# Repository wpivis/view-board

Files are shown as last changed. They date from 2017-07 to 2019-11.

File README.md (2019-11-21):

# view-board

For our very own [AnyPixel.js](http://googlecreativelab.github.io/anypixel/) board
=========

## Architecture

Project uses a Teensy 3.2 board to control the WS2812 LED strip and buttons, using serial data to communicate. 

## Install

To install the library, simply type this into your nearest console: 
```js
npm install nopixel
```

At this point, depending on the distribution, you may note that your computer is slightly unhappy. This is due to the fact that `nopixel` relies on `serialport` to get access to, well, the serial port. `serialport` however, relies on `node-gyp` which is notoriously hard to build. Therefore I recommend you go to https://github.com/nodejs/node-gyp#installation for your troubleshooting needs.

If installation of `nopixel` still fails, please run 
```js
npm install serialport
```

## Usage

- Flash the firmware found in `firmware/arduino_firmware` to the Teensy. For this you will need to install [Teensyduino](https://www.pjrc.com/teensy/teensyduino.html)
- Create a `config.json` following this template
	```json
	[{
		"comPort": "/name/of/comPort",
		"baudRate": "BAUD_RATE"
	}]
	```
- Run `node app.js` for the example app

### Canvas support

This module supports `node-canvas`. Simply create a 7x7 canvas, then export it to the board using 
```js
	var data = ctx.getImageData(0,0,7,7);
	nopixel.fromCanvas(data);
	nopixel.update();
```
For a working example, look into examples/ConnectFour

### API

#### Events

All nopixel events, with the exception of `ready`, sends back an object `eventDetail` with the coordinates of the button press in the form of 

```js
var eventDetail = {
	x: 	X-coordinate of the button press (0-6),
	y: 	Y-coordinate of the button press (0-6),
	index: 	Index of the button press (0-48)
}
```

#### `.on('ready')`

Emits when established a connection with the board. Throws an error otherwise.

#### `.on('clicked')`

Emits when a button is pressed quickly - aka 'onButtonDown'. Pass an `eventDetail` object.

#### `.on('pressed')`

Emits when a button is held down. Pass an `eventDetail` object.

#### `.on('released')`

Emits when a button is released - aka 'onButtonUp'. Pass an `eventDetail` object.

#### `.on('idle')`

Emits the default state, when nothing is happening. Pass an `eventDetail` object.

#### Functions

#### `.setPixel()`

```js
nopixel.setPixel(x, y, colorObj)
```

Where x,y denotes the coordinates on the board (0-6), and colorString is a valid `tinyColor2` object. Examples includes string input (`"black"`, `"f0f0f6"`, `"rgb (255, 0, 0)"`, `"hsla(0, 100%, 50%, .5)"`), or RGB/RGBA/HSL/HSLA/HSV/HSVA objects (`{ h: 0, s: 1, l: .5 }`)

#### `.update()`

```js
nopixel.update()
```

aka `render`. Pushes and set all changes to LEDs at the same time. This prevents multiple refresh calls to the board and saves clock cycles.

#### `.clear()`

```js
nopixel.clear()
```

Sets all pixels to black, essentially turning them off.

#### `.fromCanvas()`

```js
nopixel.fromCanvas(canvasBuffer)
```

`node-canvas` integration. Takes in a Canvas buffer and send it to the LEDs.

#### `.write()`

```js
nopixel.write(string, colorObj, scrollSpeed)
```

One of the two text writing functions. `.write()` is used for anything more than a single letter, and will scroll the text in `string`, in color `colorObj`, looping indefinitely at a speed (delay between updates) `scrollSpeed`. 

Passes back a `setInterval` object. To stop scrolling use the built-in `clearInterval()`.

For more information check out the `TextDisplay` example.

#### `.writeLetter()`

```js
nopixel.writeLetter(letter, colorObj, x, y)
```

The other text writing function. As opposed to `.write()`, `.writeLetter()` as the name suggests, only prints one `letter` at a time, in color `colorObj`, starting at coordinates `x` `y`.

Fonts configuration is stored in `letters.json` as two-dimentional arrays, with 1 as filled, and 2 as unfilled - feel free to change them as you see fit.

### Opcodes

See `commands.md`

## Future work

[ ] Emulator

[ ] Make an even bigger one!

[ ] Use pre-wired WS2812 instead of manually soldering wires

[ ] Utility buttons?

[ ] Flushed USB port

[ ] getPixelData() function

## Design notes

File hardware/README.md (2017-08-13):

# Hardware Sources

In here you will find sources for the laser-cut case and the (non-existent) PCB

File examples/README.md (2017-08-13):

# Examples

Here are some examples for you to get started with Nopixel. Make sure to run `npm install` if needed.

### Current working examples

- GameOfLife: A slightly modified version of Conway's Game of life

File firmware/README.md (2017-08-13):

# Firmware

This is the firmware for the Teensy, which is Arduino-compatible. For more information, visit [Teensy](https://www.pjrc.com/teensy/)

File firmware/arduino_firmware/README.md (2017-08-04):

## Arduino Firmwae

This Firmware uses the Arduino Keypad library - just makes sure to change `LIST_MAX` in `Keypad.h` to 49, which will allow 49-keys rollover on the view-board.

On Linux, this file can be found in `/opt/arduino/hardware/teensy/avr/libraries/Keypad/`

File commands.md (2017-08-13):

# Serial Command Manual
=========

## To Teensy

- Start bit: 128
- End bit: 173
- [Start bit] [Header] [Data] [End bit] 
- No checksum (???)

### Setting Pixel
- Opcode: 104
- [Start bit] [104] [PixelIndex] [R] [G] [B] [End bit]

### Update LEDs
- Opcode: 105
- [Start bit] [105] [End bit]

### Clear LEDs
- Opcode: 106
- [Start bit] [106] [End bit]

### Setting multiple pixels
- Opcode: 107
- [Start bit] [107] [startPx] [endPx] [r1] [g1] [b1] .... [rn] [gn] [bn] [end bit]

## From Teensy

- [Start bit] [n-byte] [Data] [Checksum]
- [n-byte] = number of bytes from Data to Checksum, inclusively
- Checksum following Fletcher-8: Sum(Start bit, n-byte, data, checksum) & 0xFF = 1

### Button Events
- Opcode: 19 (0x13)
- [0x13] [3] [ButtonIndex] [ButtonStatus] [Checksum]

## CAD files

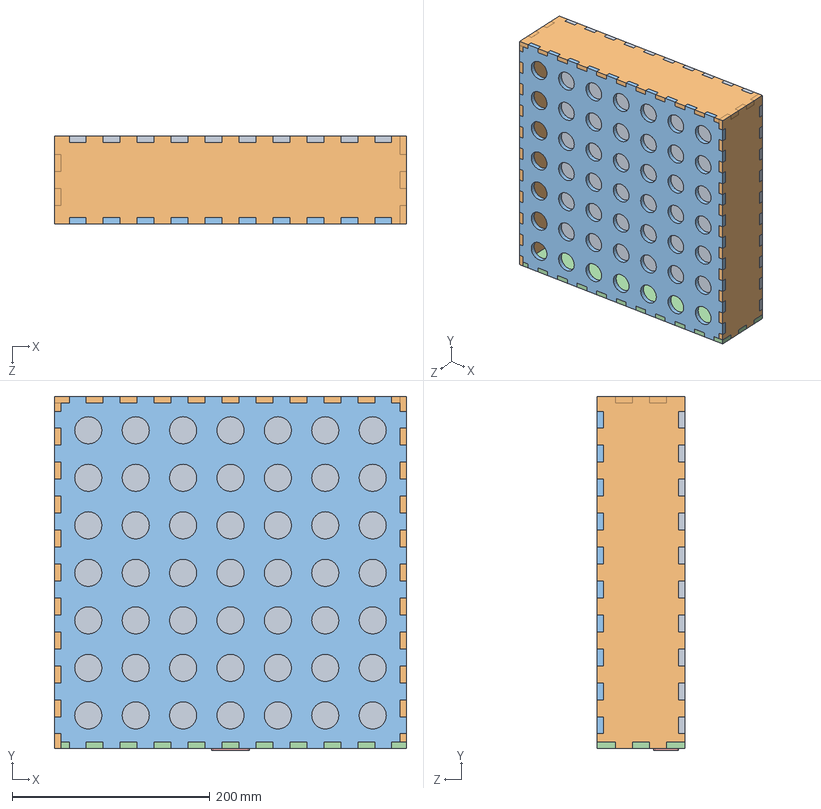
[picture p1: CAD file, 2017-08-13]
hardware/mechanical/assembly.SLDASM
355.6 x 357.6 x 88.9 mm
bottom
side x 3
top
side-port
adapter

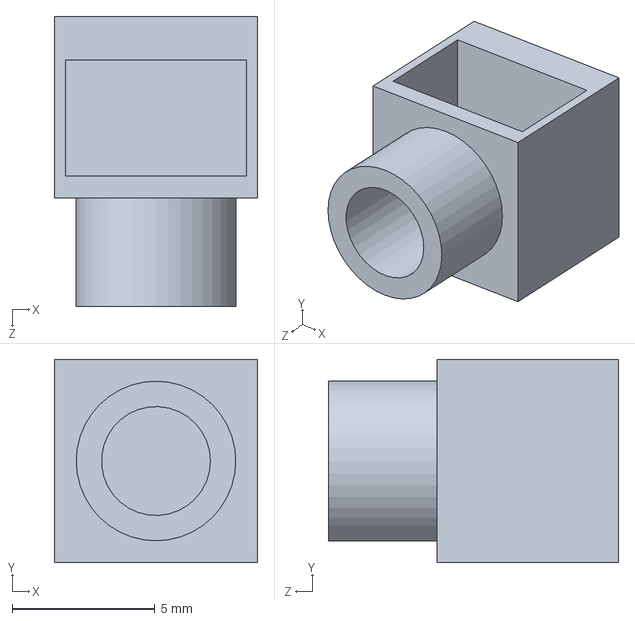
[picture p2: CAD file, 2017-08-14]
hardware/mechanical/button-holder.SLDPRT
7.11 x 7.11 x 10.2 mm

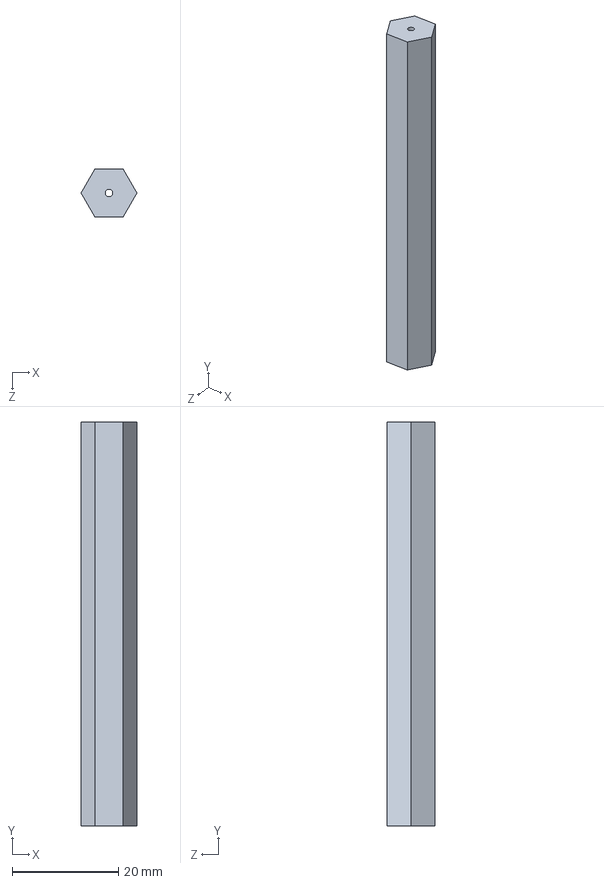
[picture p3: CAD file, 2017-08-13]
hardware/mechanical/standoffs.SLDPRT
10.6 x 76.2 x 9.14 mm

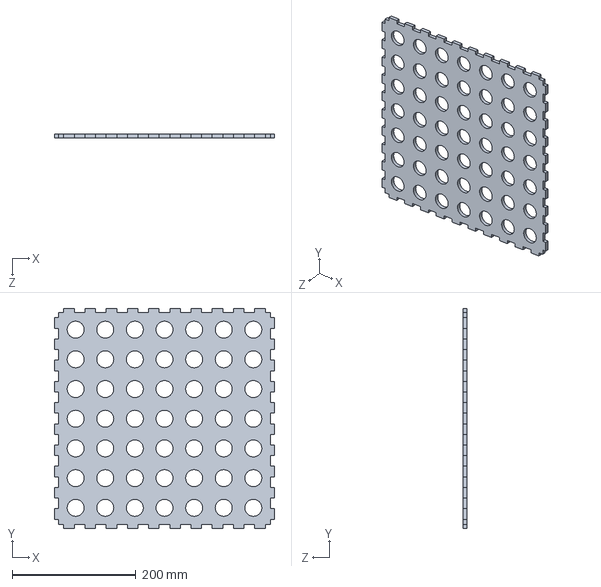
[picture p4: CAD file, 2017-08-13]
hardware/mechanical/top.SLDPRT
355.6 x 355.6 x 6.35 mm

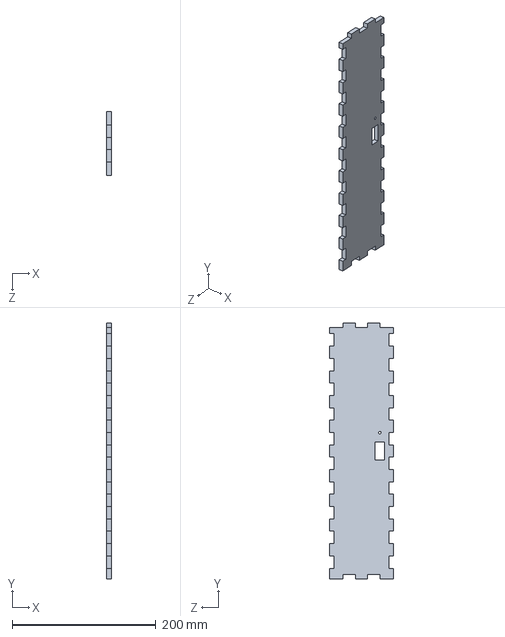
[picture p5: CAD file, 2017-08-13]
hardware/mechanical/side-port.SLDPRT
6.35 x 355.6 x 88.9 mm

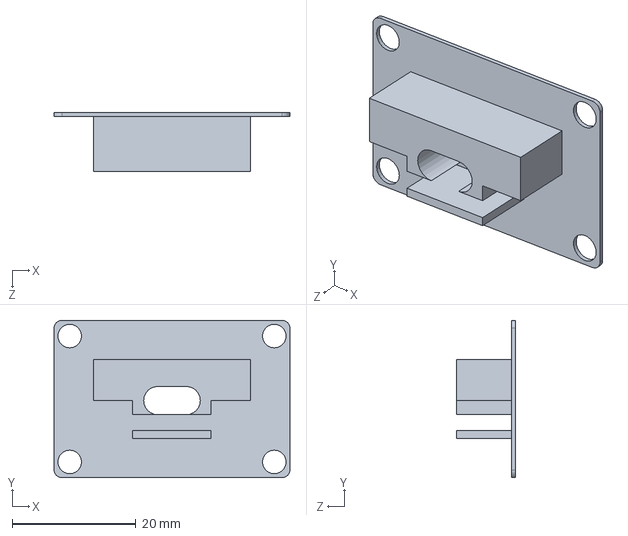
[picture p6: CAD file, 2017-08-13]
hardware/mechanical/adapter.SLDPRT
38.1 x 25.4 x 9.49 mm

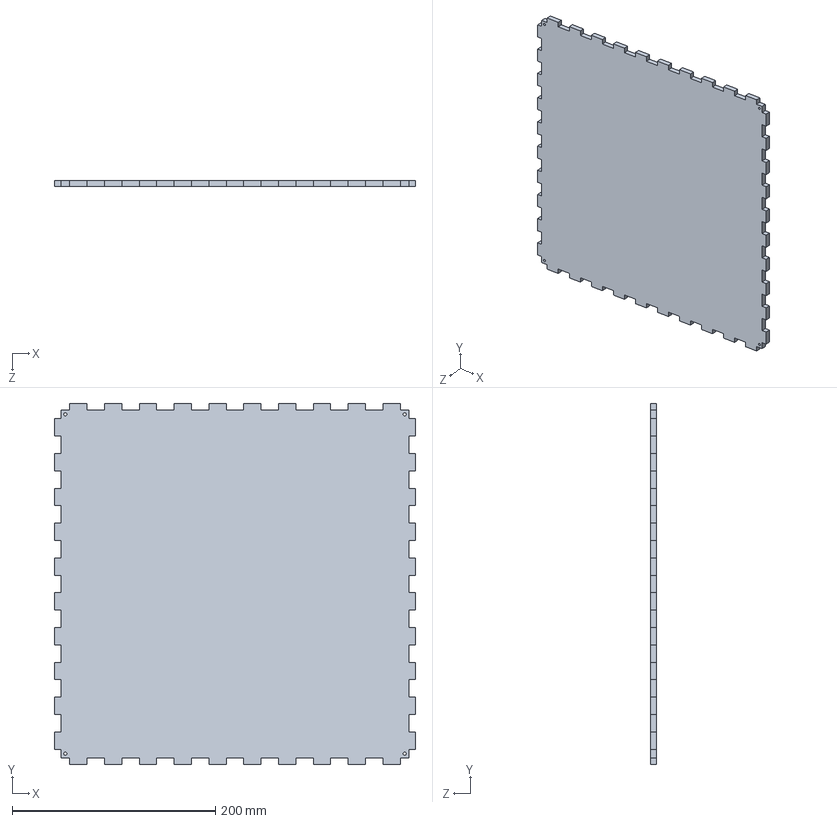
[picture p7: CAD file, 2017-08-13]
hardware/mechanical/bottom.SLDPRT
355.6 x 355.6 x 6.35 mm

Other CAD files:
hardware/mechanical/side.SLDPRT
hardware/mechanical/adapter.STL
hardware/mechanical/assembly.SLDDRW
hardware/mechanical/button-holder.STL
hardware/mechanical/dwg/bottom.DWG
hardware/mechanical/dwg/bottom.DXF
hardware/mechanical/dwg/side-port.DWG
hardware/mechanical/dwg/side-port.DXF
hardware/mechanical/dwg/side.DWG
hardware/mechanical/dwg/side.DXF
hardware/mechanical/dwg/top.DWG
hardware/mechanical/dwg/top.DXF
hardware/mechanical/standoffs.STL

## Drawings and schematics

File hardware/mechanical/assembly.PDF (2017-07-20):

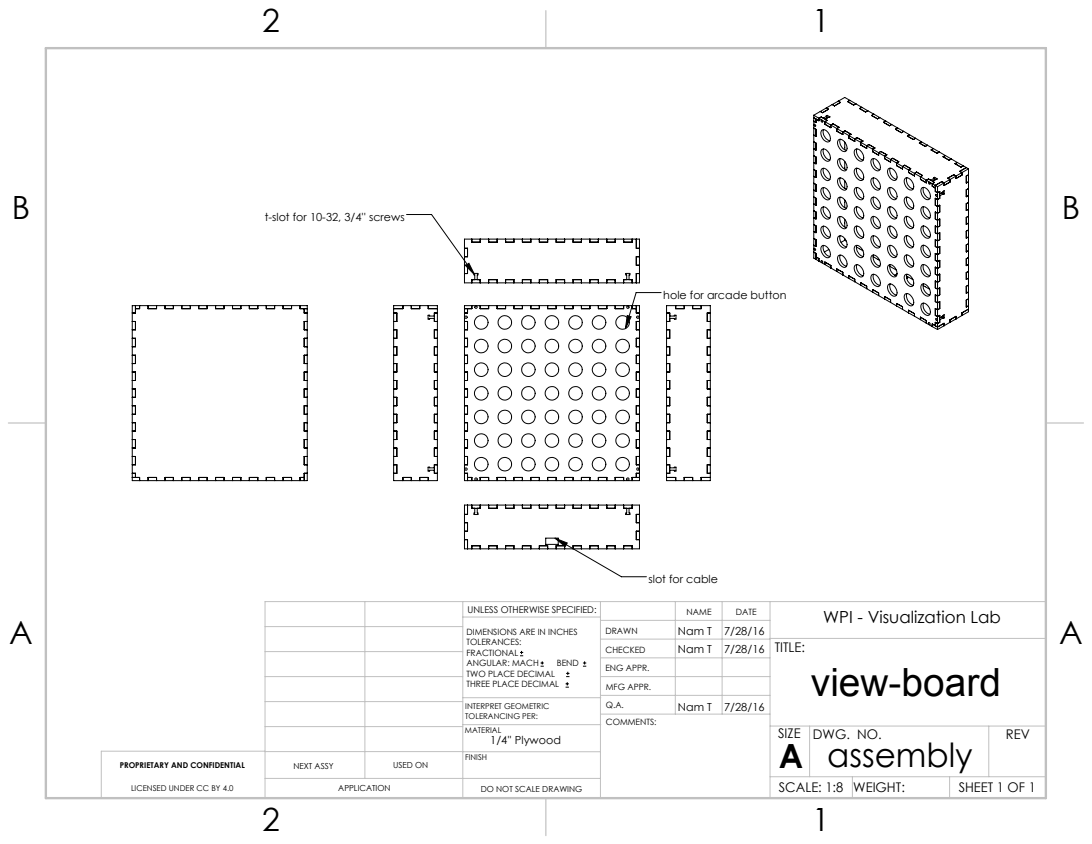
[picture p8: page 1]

t-slot for 10-32, 3/4'' screws

hole for arcade button

slot for cable

UNLESS OTHERWISE SPECIFIED: | | NAME | DATE | WPI - Visualization Lab
DIMENSIONS ARE IN INCHES TOLERANCES: FRACTIONAL ANGULAR: MACH BEND TWO PLACE DECIMAL THREE PLACE DECIMAL | DRAWN | Nam T | 7/28/16
CHECKED | Nam T | 7/28/16 | TITLE: view-board

ENG APPR.
MFG APPR.

INTERPRET GEOMETRIC TOLERANCING PER: | Q.A. | Nam T | 7/28/16
MATERIAL 1/4'' Plywood | | SIZE A | DWG. NO. assembly | REV

PROPRIETARY AND CONFIDENTIAL LICENSED UNDER CC BY 4.0 | NEXT ASSY | USED ON | FINISH

APPLICATION | DO NOT SCALE DRAWING | | SCALE: 1:8 | WEIGHT: | SHEET 1 OF 1

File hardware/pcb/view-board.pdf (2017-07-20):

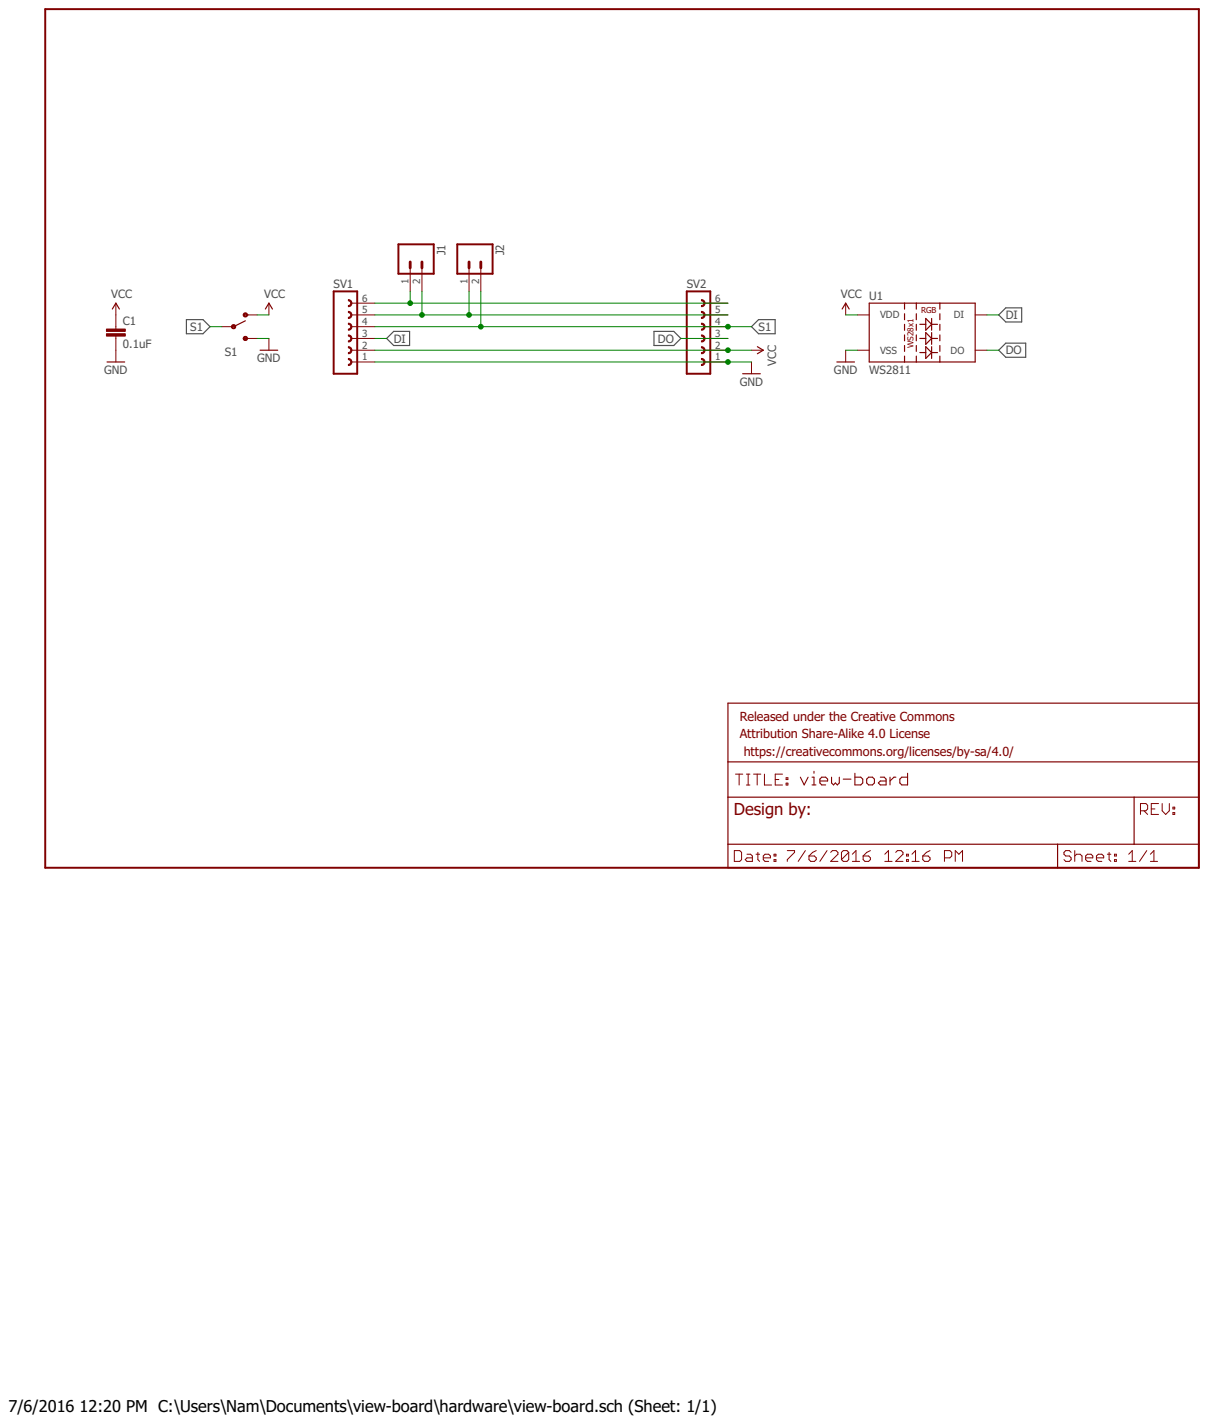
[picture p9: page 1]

Released under the Creative Commons Attribution Share-Alike 4.0 License https://creativecommons.org/licenses/by-sa/4.0/

7/6/2016 12:20 PM C:\Users\Nam\Documents\view-board\hardware\view-board.sch (Sheet: 1/1)

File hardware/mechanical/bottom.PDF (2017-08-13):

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

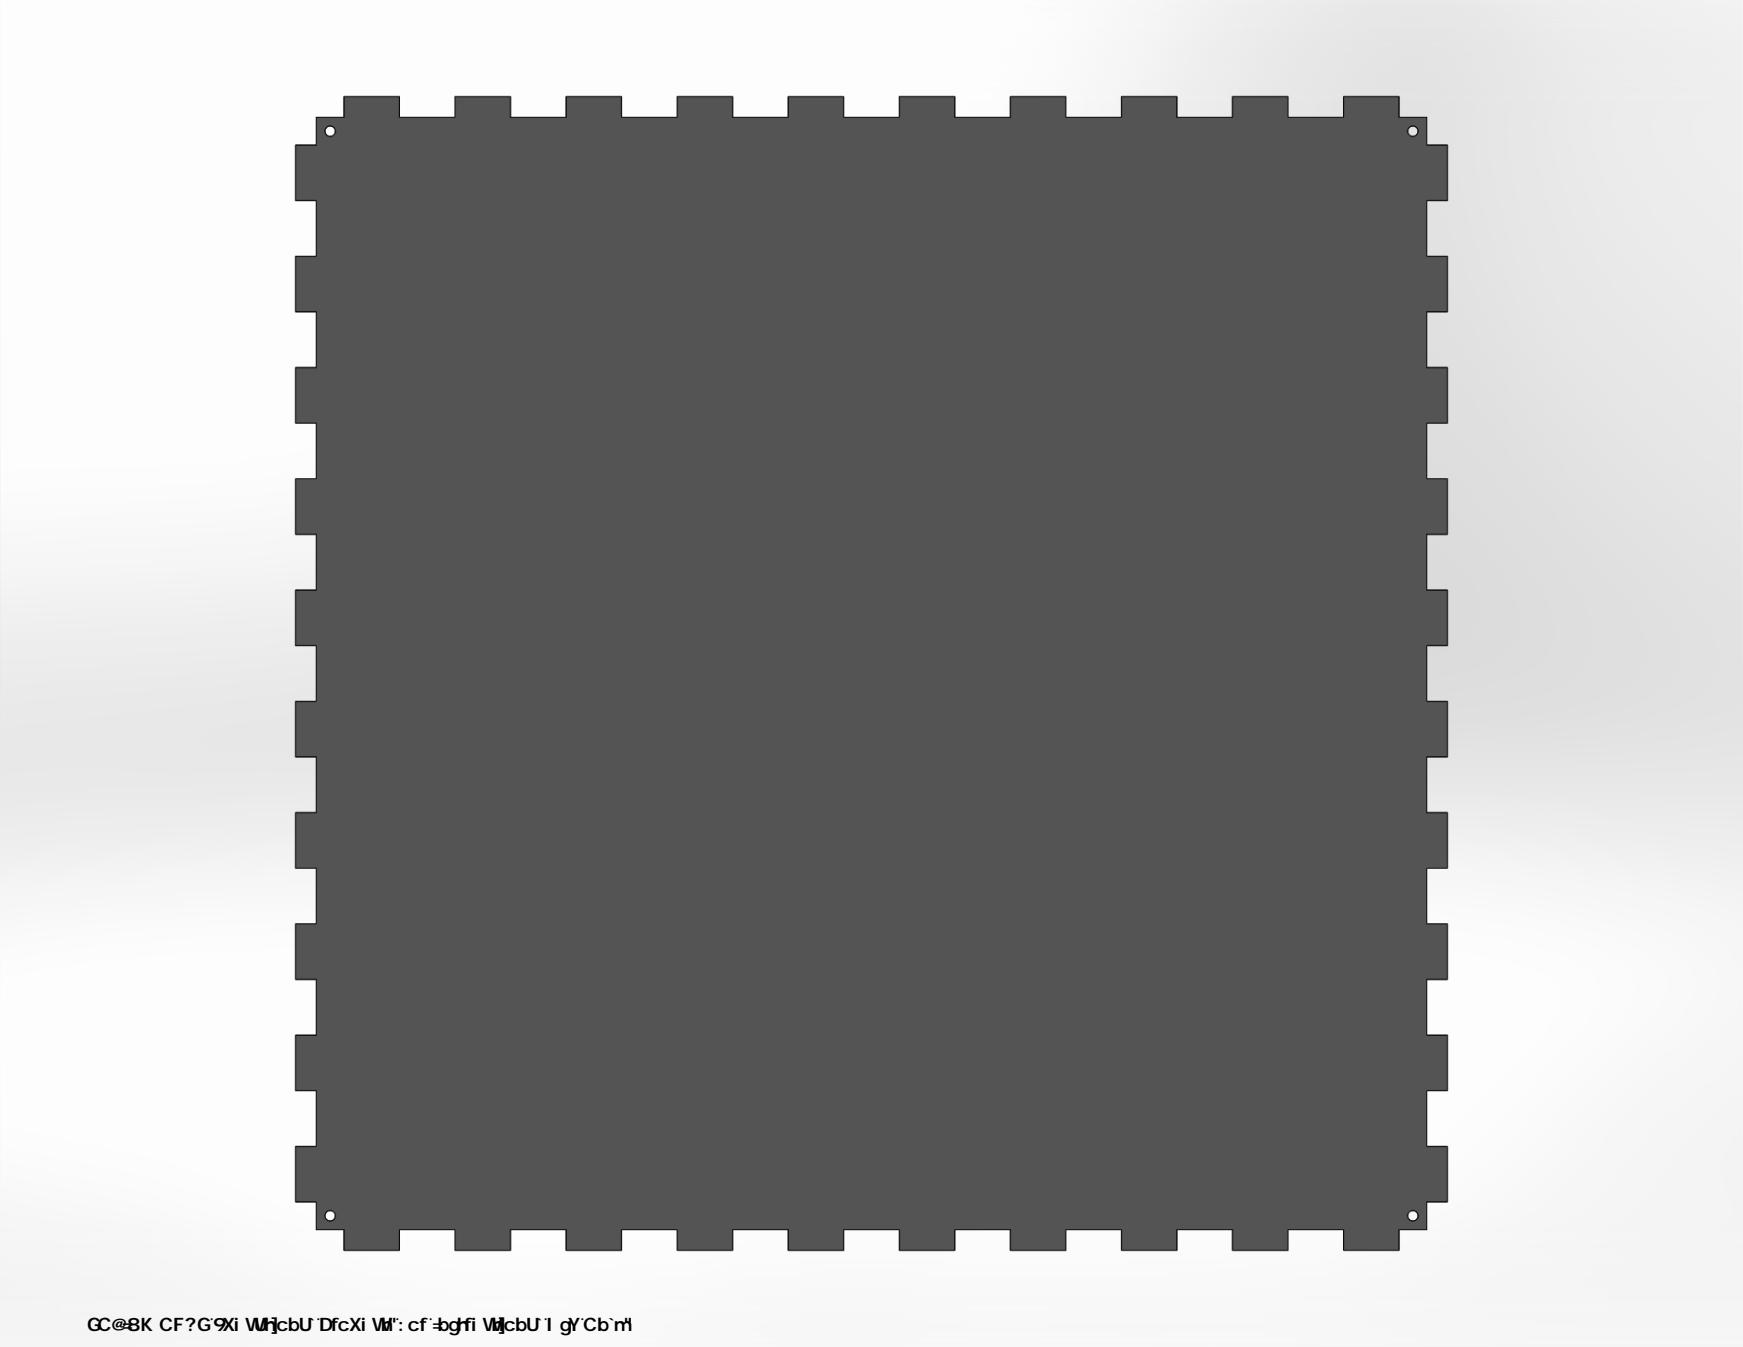
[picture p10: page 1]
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

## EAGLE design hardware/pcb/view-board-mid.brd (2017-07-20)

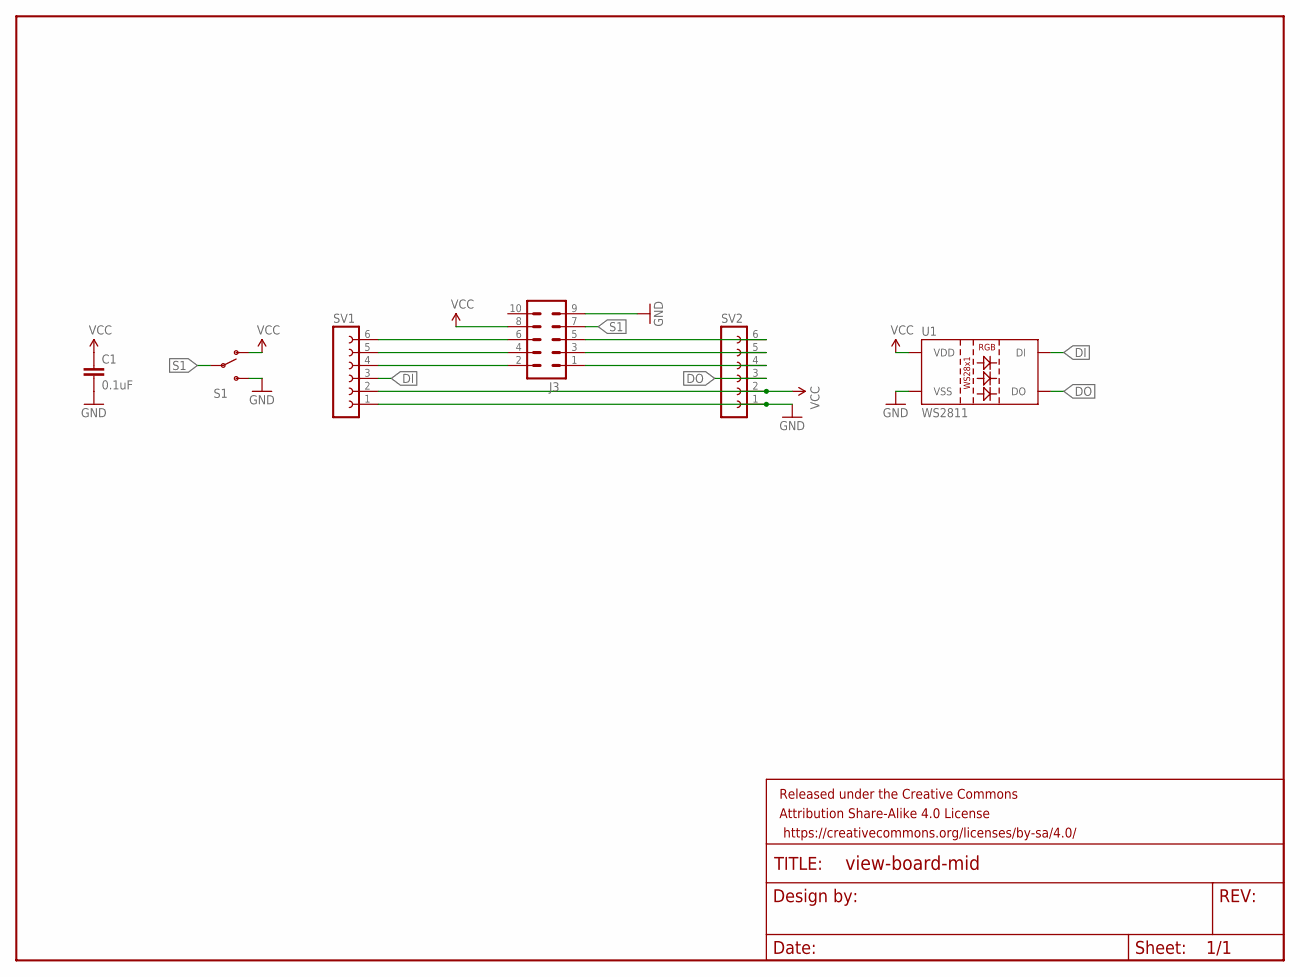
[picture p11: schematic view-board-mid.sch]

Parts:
C1: 0.1uF; 0805
FRAME1: FRAME-LETTER; CREATIVE_COMMONS
J3: M05X2SHD; 2X5-SHROUDED
S1: SWITCH-SPDTPTH; SWITCH-SPDT
SV1, SV2: FE06-1; FE06
U1: WS2811; LED-TRICOLOR-5050-IC

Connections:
DI: SV1.3, U1.2 (DI)
DO: SV2.3, U1.1 (DO)
GND: C1.2, J3.9, S1.3 (S), SV1.1, SV2.1, U1.6 (VSS)
unnamed: J3.2, SV1.4
unnamed: J3.1, SV2.4
unnamed: J3.3, SV2.5
unnamed: J3.4, SV1.5
unnamed: J3.6, SV1.6
unnamed: J3.5, SV2.6
S1: J3.7, S1.2
VCC: C1.1, J3.8, S1.1 (O), SV1.2, SV2.2, U1.3 (VDD), U1.5 (VDD)

Board: 2 copper layers, 7 parts (0 on the bottom side), 11 nets, no tracks yet.

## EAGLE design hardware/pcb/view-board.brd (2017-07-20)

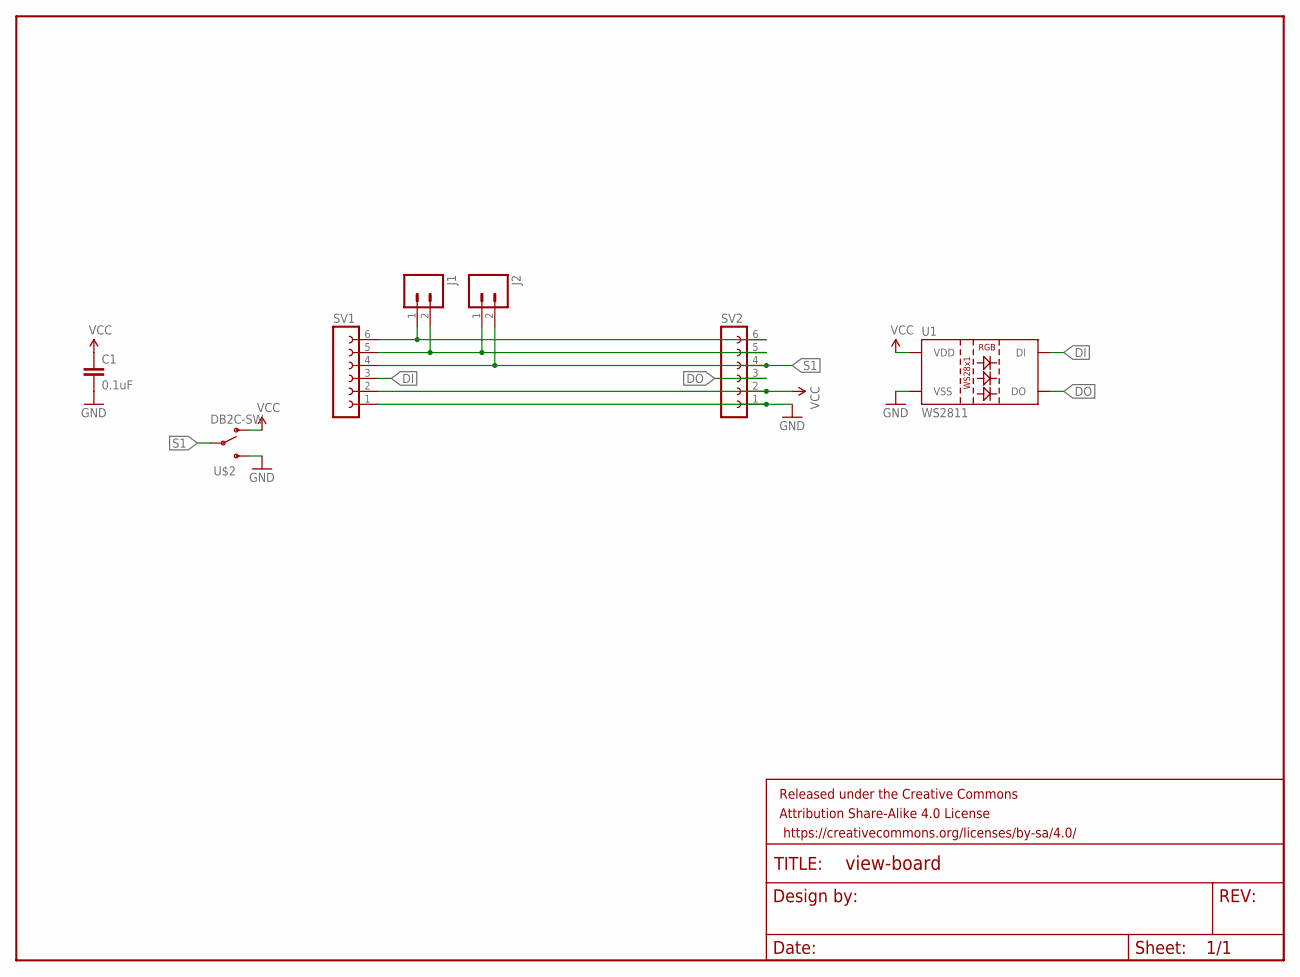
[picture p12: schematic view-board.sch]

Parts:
C1: 0.1uF; 0805
FRAME1: FRAME-LETTER; CREATIVE_COMMONS
J1, J2: M02LOCK; 1X02_LOCK
SV1, SV2: FE06-1; FE06
U1: WS2811; LED-TRICOLOR-5050-IC
U$2: DB2C-SW; CHERRY-DB2C

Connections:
DI: SV1.3, U1.2 (DI)
DO: SV2.3, U1.1 (DO)
GND: C1.2, SV1.1, SV2.1, U1.6 (VSS), U$2.3 (S)
unnamed: J1.1, SV1.6, SV2.6
unnamed: J1.2, J2.1, SV1.5, SV2.5
S1: J2.2, SV1.4, SV2.4, U$2.2
VCC: C1.1, SV1.2, SV2.2, U1.3 (VDD), U1.5 (VDD), U$2.1 (O)

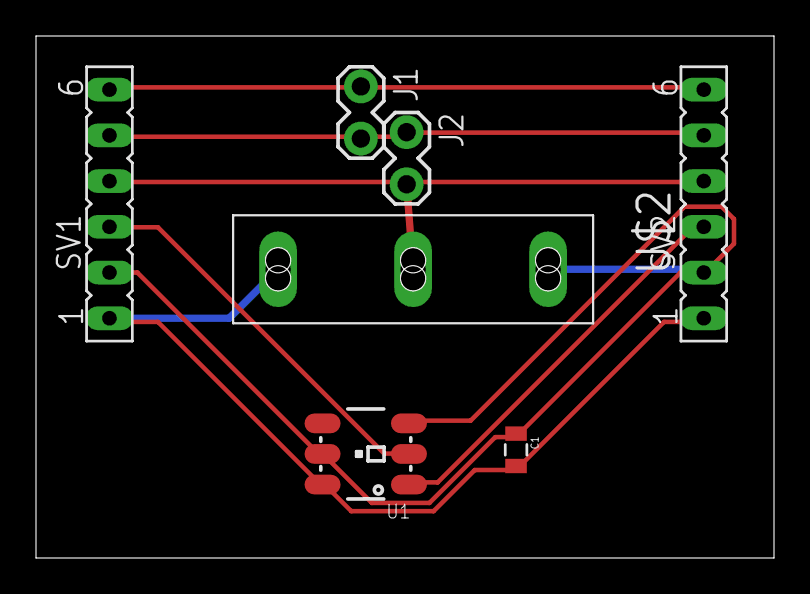
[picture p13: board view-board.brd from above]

Board: 2 copper layers, 41.0 x 29.0 mm, 8 parts (0 on the bottom side), 7 nets.

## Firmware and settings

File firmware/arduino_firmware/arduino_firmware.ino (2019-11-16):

#include "FastLED.h"
#include <Keypad.h>

#define NUM_LEDS 49
#define DATA_PIN 15
#define BAUD_RATE 115200

CRGB leds[NUM_LEDS];

const byte ROWS = 7; //four rows
const byte COLS = 7; //three columns
char keys[ROWS][COLS] = {
  {0, 7, 14, 21, 28, 35, 42},
  {1, 8, 15, 22, 29, 36, 43},
  {2, 9, 16, 23, 30, 37, 44},
  {3, 10, 17, 24, 31, 38, 45},
  {4, 11, 18, 25, 32, 39, 46},
  {5, 12, 19, 26, 33, 40, 47},
  {6, 13, 20, 27, 34, 41, 48}
};

byte rowPins[ROWS] = {17,2 ,3 ,4 ,5 ,6 ,7 }; //connect to the row pinouts of the keypad
byte colPins[COLS] = {8 ,9 ,10,11,12,16,14}; //connect to the column pinouts of the keypad

Keypad kpd = Keypad( makeKeymap(keys), rowPins, colPins, ROWS, COLS );

const byte numChars = 152;
char receivedChars[numChars];

boolean newData = false;

void setup() {
  Serial.begin(BAUD_RATE);
  Serial.setTimeout(50);
  kpd.setDebounceTime(1);
  FastLED.addLeds<NEOPIXEL, DATA_PIN>(leds, NUM_LEDS);
  FastLED.setMaxPowerInVoltsAndMilliamps(5,500); 

}

unsigned long loopCount = 0;
unsigned long startTime = millis();
byte msg = 99;

//int incomingByte;

void loop() {
  loopCount++;
  if ( (millis() - startTime) > 1000 ) {
    //      Serial.println(loopCount);
    startTime = millis();
    loopCount = 0;
  }

  // Fills kpd.key[ ] array with up-to 10 active keys.
  // Returns true if there are ANY active keys.
  if (kpd.getKeys()) {
    for (int i = 0; i < LIST_MAX; i++) // Scan the whole key list.
    {
      if ( kpd.key[i].stateChanged )   // Only find keys that have changed state.
      {
        switch (kpd.key[i].kstate) {  // Report active key state : IDLE, PRESSED, HOLD, or RELEASED
          case PRESSED:
            msg = 0;
//            leds[kpd.key[i].kchar] = CHSV(random8(), 255, 255);
            break;
          case HOLD:
            msg = 1;
//            leds[kpd.key[i].kchar] = CRGB::Black;
            break;
          case RELEASED:
            msg = 2;
            //                leds[kpd.key[i].kchar] = CRGB::Black;
            break;
          case IDLE:
            msg = 3;
        }
        //        Serial.print("Key ");
        byte message[] = {19, 3, 99, 99, 99};
        message[2] = kpd.key[i].kchar;
        message[3] = msg;
        message[4] = 256 - 19 - 3 - kpd.key[i].kchar - msg;
        Serial.write(message, 5);
      }
    }
  }

    recvWithStartEndMarkers();
    parseCommand();
}


void recvWithStartEndMarkers() {
    static boolean recvInProgress = false;
    static byte ndx = 0;
    char startMarker = 128;
    char endMarker = 173;
    char rc;
 
 // This command is blocking - fix it???
 // Fixed it - haven't tested if any packets are lost this way..
    if (Serial.available() > 0 && newData == false) {
        rc = Serial.read();

        if (recvInProgress == true) {
            if (rc != endMarker) {
                receivedChars[ndx] = rc;
                ndx++;
                if (ndx >= numChars) {
                    ndx = numChars - 1;
                }
            }
            else {
                receivedChars[ndx] = '\0'; // terminate the string
                recvInProgress = false;
                ndx = 0;
                newData = true;
            }
        }

        else if (rc == startMarker) {
            recvInProgress = true;
        }
    }
}

void parseCommand() {
    if (newData) {
        // Command would be stored in receivedChars[]
        switch (receivedChars[0]) {
          case 104: //Set a specific pixel to a color. First bit is pixel address, next 3 bits are RGB values.
          leds[receivedChars[1]].r = receivedChars[2];
          leds[receivedChars[1]].g = receivedChars[3];
          leds[receivedChars[1]].b = receivedChars[4];
          break;

          case 105: //Refresh
          FastLED.show();
          break;

          case 106: //Clear
          fill_solid(leds, NUM_LEDS, CRGB::Black);
          break;

          case 107: //Set multiple LEDs
          // For crying out loud someone please implement a safety check please and thank you.
          for (int i=0; i<49; i++) {
            leds[i].r = receivedChars[i*3+3];
            leds[i].g = receivedChars[i*3+4];
            leds[i].b = receivedChars[i*3+5];          
          }
          break;
        }
        newData = false;
    }
}

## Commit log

2016-06-20 Hackiest way ever - working square floats for demo board
2016-06-20 Board selection on mouse down
2016-06-29 Changed button structure
2017-07-20 Old stuff. Prepare for major rewrite.
    [assembly.SLDASM, assembly.SLDDRW, bottom.DWG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]
2017-08-04 Prototype working unter ./test/
2017-08-05 Fixed blocking statement in firmware
    [arduino_firmware.ino]
2017-08-10 Reworked frame setter, increased buffer
    [arduino_firmware.ino]
2017-08-13 Updated mechanical design, added standoffs and usb adapter
    [adapter.SLDPRT, adapter.STL, assembly.SLDASM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]
2017-08-14 Fixed button holder
    [button-holder.SLDPRT, button-holder.STL]
2019-11-16 Multiple factoring in both library, software and example app(s)
    This is a big commit that I should've done sooner.
    Software-wise, I went through the `nopixel` library and cleaned up the code, added constant for opcodes instead of magic numbers, wrote more descriptive console log and added a `ready` event that will make life much more bearable.
    Hardware wise, I swapped a couple of pins on the Teensy board, mainly
    because the old Teensy 2.0 board burned out and I had to replace it with
    the newer Teensy 3.2. Expect more pin changes in the future. Also I
    don't understand why Arduino straight up replaced the file instead of
    line-by-line diff.
    Example-wise I cleaned up the `app.js` in root a bi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
    [arduino_firmware.ino]
2019-11-17 Finished HelloWorld example
    Fixed a quick bug that stems from shoddy opcode decision. Added a hello
    world example that randomizes colors on the board and independently
    changes them.
2019-11-18 Minor QoL improvements to TextDisplay, quick 'ready' event fix and README update
    'ready' event used to be hardcoded to emit 1 millisecond after we
    initiate connection. This, in every single aspects, was not a good idea.
    But it worked.
    After actually bothering to look at the node `serialport` library, I
    added a passthrough 'read' event without the need for hardcoding.
    You're welcome, past me.

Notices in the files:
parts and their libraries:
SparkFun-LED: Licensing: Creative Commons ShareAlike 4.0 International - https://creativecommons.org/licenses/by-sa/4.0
